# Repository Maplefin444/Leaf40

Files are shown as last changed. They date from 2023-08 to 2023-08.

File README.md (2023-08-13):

# Leaf40
This is my custom split spacebar 40% keyboard, with a custom PCB, and a 3D printed case.

***This is a work in progress, this repository houses all files pertaining to the project.***

## Parts List
- [ ] PCB
- [ ] Case
- [ ] Plate
- [ ] Keycaps
- [ ] MX-Style Switches
- [ ] SOD-123 diodes (44 total)
- [ ] Arduino Pro Micro
- [ ] Screw-in Stabilizers (2x2u)

## Layout
The layout can be found in the `Keyboard Layout` directory.

Layer 0 is the default layer, while each layer will have the corresponding layer switch keys darkened.

As of right now, non-zero layers are a ***work in progress and will change.***

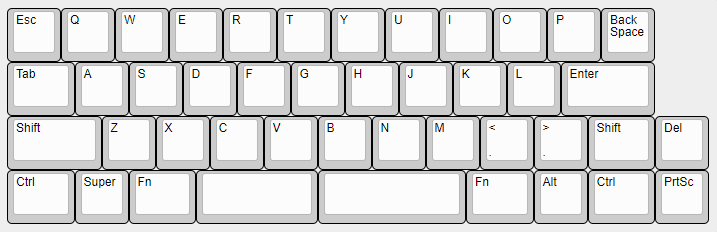
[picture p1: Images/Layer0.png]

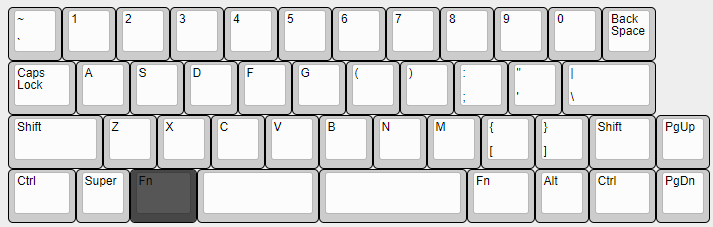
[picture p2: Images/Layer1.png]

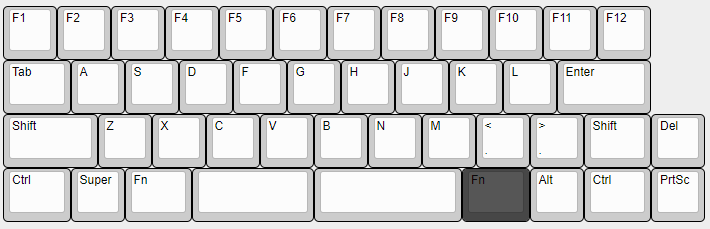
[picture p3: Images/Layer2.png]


## PCB
The PCB was designed on KiCad and can be found in the `PCB` directory.

MarbastLib is required to have the MX switch footprints.

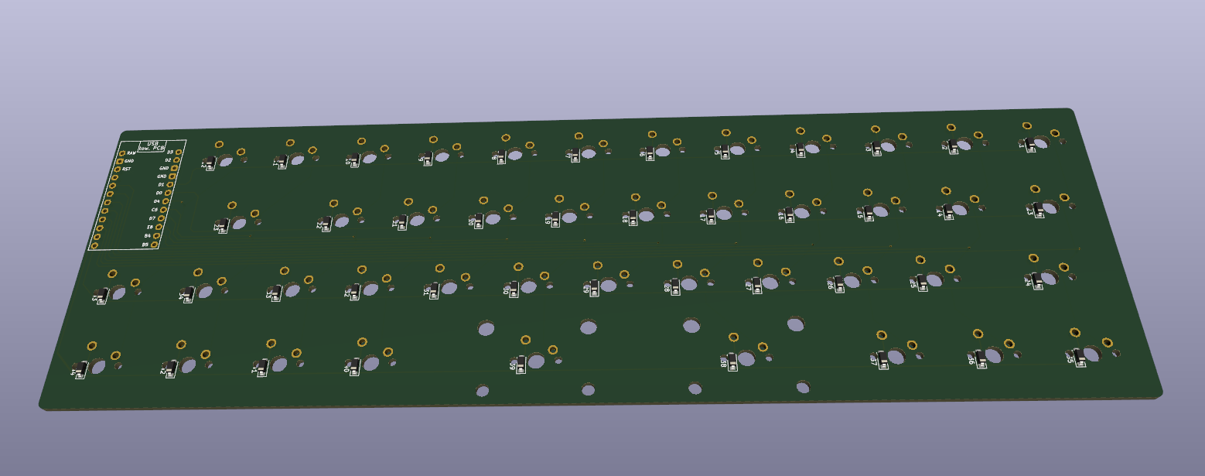
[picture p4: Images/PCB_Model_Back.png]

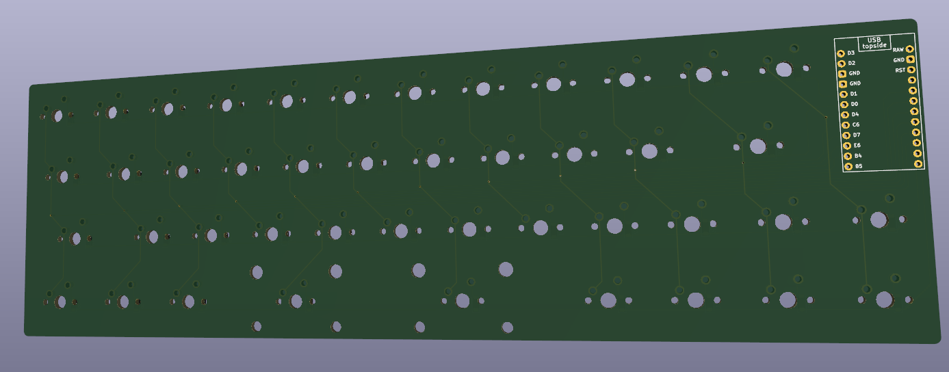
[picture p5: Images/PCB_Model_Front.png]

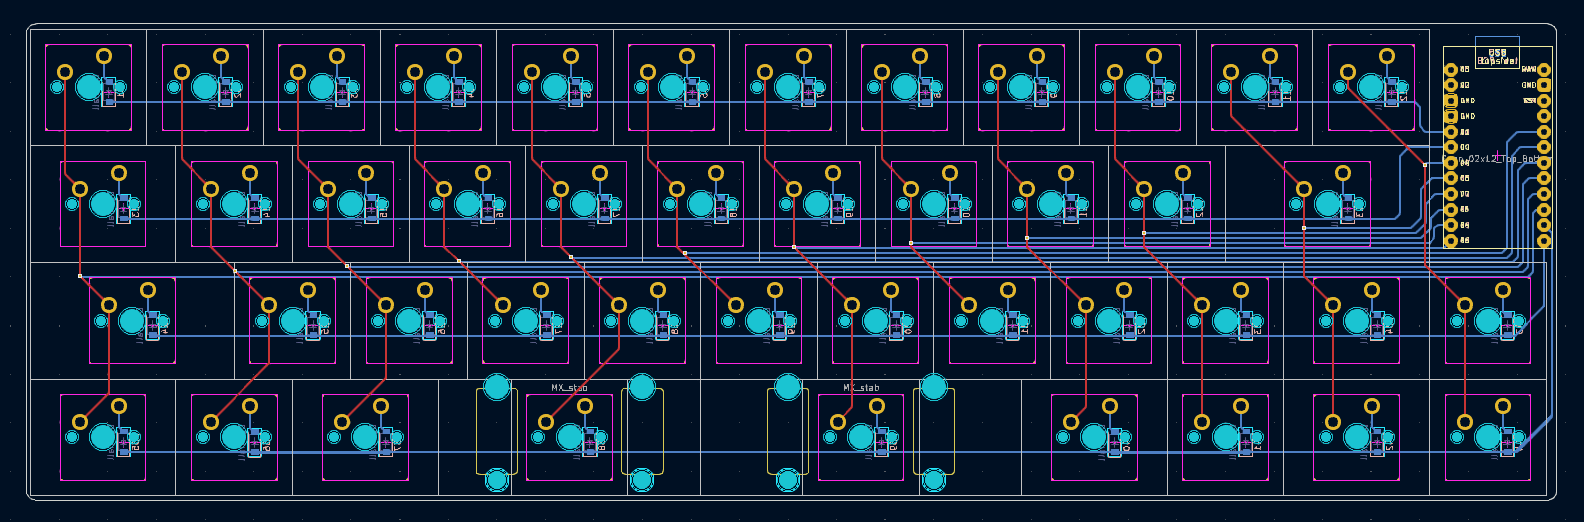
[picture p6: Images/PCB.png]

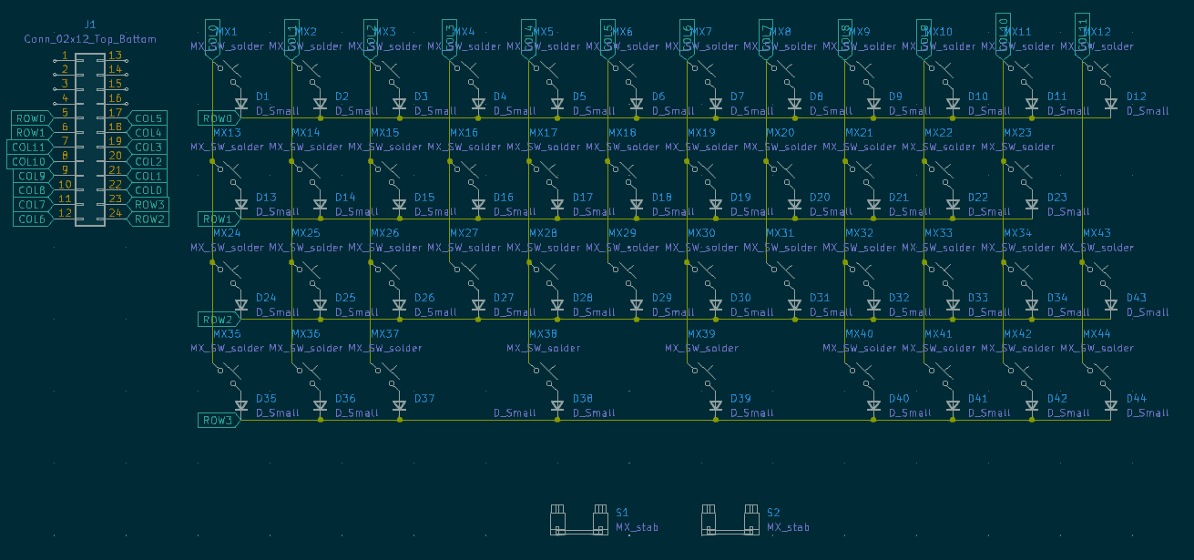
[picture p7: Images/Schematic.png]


## Firmware

This keyboard supports QMK and Vial. Both files can be found in the `Firmware` directory, `default` for regular QMK, and `vial` for the Vial firmware.

These firmwares can be flashed using the QMK Toolbox. 

The QMK firmware has ASCII art for the keyboard layouts, for ease of editing.

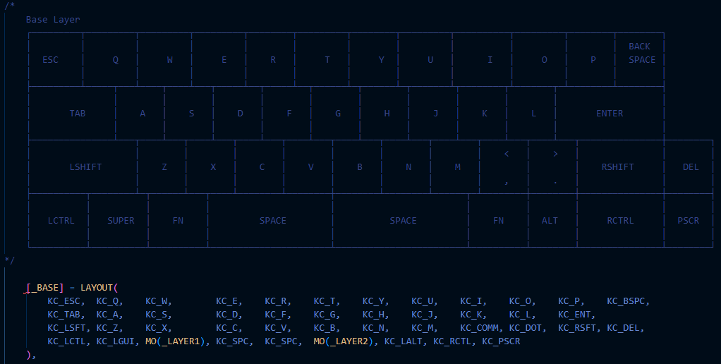
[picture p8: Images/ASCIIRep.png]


### Flashing QMK Firmware
Add the `default` keymap, info JSON, and rules file into a directory named `leaf40` under `keyboards` in your QMK directory. Then, compile using `qmk compile -kb leaf40 -km default`. Flash using QMK Toolbox.

### Flashing Vial Firmware
Add the `vial` keymap, info JSON, and rules file into a directory named `leaf40` under `keyboards` in your Vial directory. Then, compile using `make leaf40:vial` in your `vial-qmk` directory. Flash using QMK Toolbox.

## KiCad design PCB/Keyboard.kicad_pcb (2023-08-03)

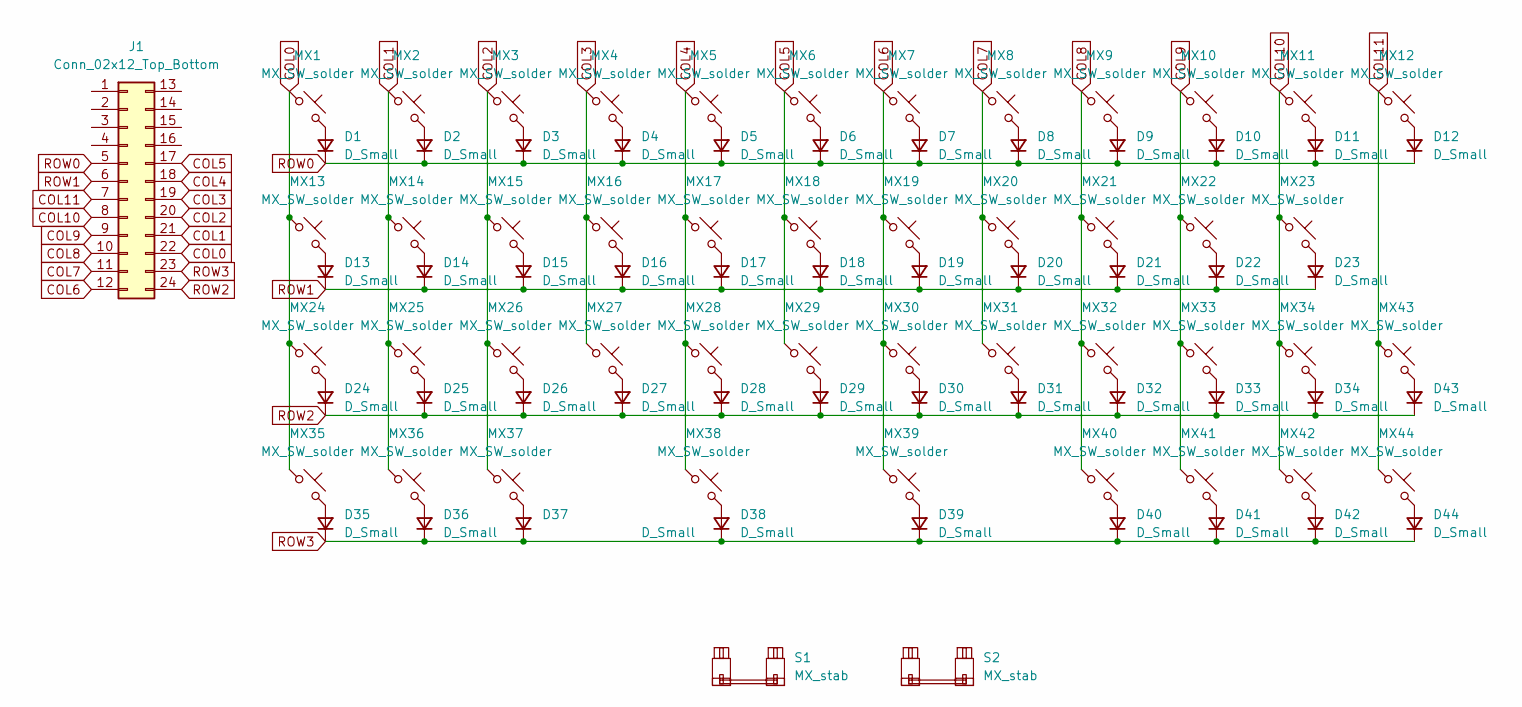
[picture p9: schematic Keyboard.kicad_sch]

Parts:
D1, D2, D3, D4, D5, D6, D7, D8, D9, D10, D11, D12, D13, D14, D15, D16, D17, D18, D19, D20, D21, D22, D23, D24, D25, D26, D27, D28, D29, D30, D31, D32, D33, D34, D35, D36, D37, D38, D39, D40, D41, D42, D43, D44: D_Small; D_SOD-123
J1: Conn_02x12_Top_Bottom; ProMicro_Reversible_Single
MX1, MX2, MX3, MX4, MX5, MX6, MX7, MX8, MX9, MX10, MX11, MX12, MX14, MX15, MX16, MX17, MX18, MX19, MX20, MX21, MX22, MX25, MX26, MX27, MX28, MX29, MX30, MX31, MX32, MX33, MX36, MX38, MX39, MX41, MX43, MX44: MX_SW_solder; SW_MX_1u
MX13, MX34, MX35, MX37, MX40, MX42: MX_SW_solder; SW_MX_1.25u
MX23, MX24: MX_SW_solder; SW_MX_1.75u
S1: MX_stab; STAB_MX_2.25u
S2: MX_stab; STAB_MX_2.75u

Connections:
COL0: J1.22, MX1.1, MX13.1, MX24.1, MX35.1
COL1: J1.21, MX2.1, MX14.1, MX25.1, MX36.1
COL2: J1.20, MX3.1, MX15.1, MX26.1, MX37.1
COL3: J1.19, MX4.1, MX16.1, MX27.1
COL4: J1.18, MX5.1, MX17.1, MX28.1, MX38.1
COL5: J1.17, MX6.1, MX18.1, MX29.1
COL6: J1.12, MX7.1, MX19.1, MX30.1, MX39.1
COL7: J1.11, MX8.1, MX20.1, MX31.1
COL8: J1.10, MX9.1, MX21.1, MX32.1, MX40.1
COL9: J1.9, MX10.1, MX22.1, MX33.1, MX41.1
COL10: J1.8, MX11.1, MX23.1, MX34.1, MX42.1
COL11: J1.7, MX12.1, MX43.1, MX44.1
unnamed: D1.2 (A), MX1.2
unnamed: D2.2 (A), MX2.2
unnamed: D3.2 (A), MX3.2
unnamed: D4.2 (A), MX4.2
unnamed: D5.2 (A), MX5.2
unnamed: D6.2 (A), MX6.2
unnamed: D7.2 (A), MX7.2
unnamed: D8.2 (A), MX8.2
unnamed: D9.2 (A), MX9.2
unnamed: D10.2 (A), MX10.2
unnamed: D11.2 (A), MX11.2
unnamed: D12.2 (A), MX12.2
unnamed: D13.2 (A), MX13.2
unnamed: D14.2 (A), MX14.2
unnamed: D15.2 (A), MX15.2
unnamed: D16.2 (A), MX16.2
unnamed: D17.2 (A), MX17.2
unnamed: D18.2 (A), MX18.2
unnamed: D19.2 (A), MX19.2
unnamed: D20.2 (A), MX20.2
unnamed: D21.2 (A), MX21.2
unnamed: D22.2 (A), MX22.2
unnamed: D23.2 (A), MX23.2
unnamed: D24.2 (A), MX24.2
unnamed: D25.2 (A), MX25.2
unnamed: D26.2 (A), MX26.2
unnamed: D27.2 (A), MX27.2
unnamed: D28.2 (A), MX28.2
unnamed: D29.2 (A), MX29.2
unnamed: D30.2 (A), MX30.2
unnamed: D31.2 (A), MX31.2
unnamed: D32.2 (A), MX32.2
unnamed: D33.2 (A), MX33.2
unnamed: D34.2 (A), MX34.2
unnamed: D35.2 (A), MX35.2
unnamed: D36.2 (A), MX36.2
unnamed: D37.2 (A), MX37.2
unnamed: D38.2 (A), MX38.2
unnamed: D39.2 (A), MX39.2
unnamed: D40.2 (A), MX40.2
unnamed: D41.2 (A), MX41.2
unnamed: D42.2 (A), MX42.2
unnamed: D43.2 (A), MX43.2
unnamed: D44.2 (A), MX44.2
ROW0: D1.1 (K), D2.1 (K), D3.1 (K), D4.1 (K), D5.1 (K), D6.1 (K), D7.1 (K), D8.1 (K), D9.1 (K), D10.1 (K), D11.1 (K), D12.1 (K), J1.5
ROW1: D13.1 (K), D14.1 (K), D15.1 (K), D16.1 (K), D17.1 (K), D18.1 (K), D19.1 (K), D20.1 (K), D21.1 (K), D22.1 (K), D23.1 (K), J1.6
ROW2: D24.1 (K), D25.1 (K), D26.1 (K), D27.1 (K), D28.1 (K), D29.1 (K), D30.1 (K), D31.1 (K), D32.1 (K), D33.1 (K), D34.1 (K), D43.1 (K), J1.24
ROW3: D35.1 (K), D36.1 (K), D37.1 (K), D38.1 (K), D39.1 (K), D40.1 (K), D41.1 (K), D42.1 (K), D44.1 (K), J1.23

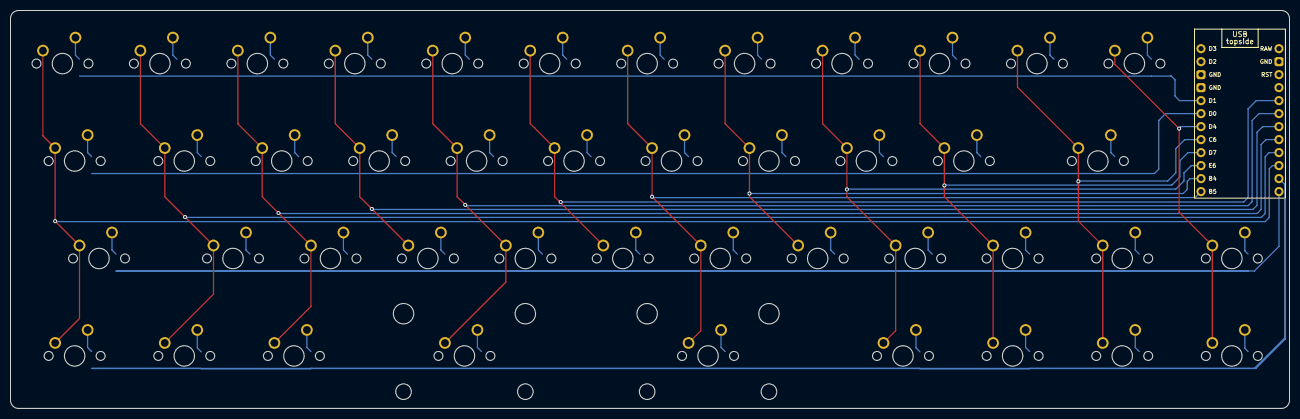
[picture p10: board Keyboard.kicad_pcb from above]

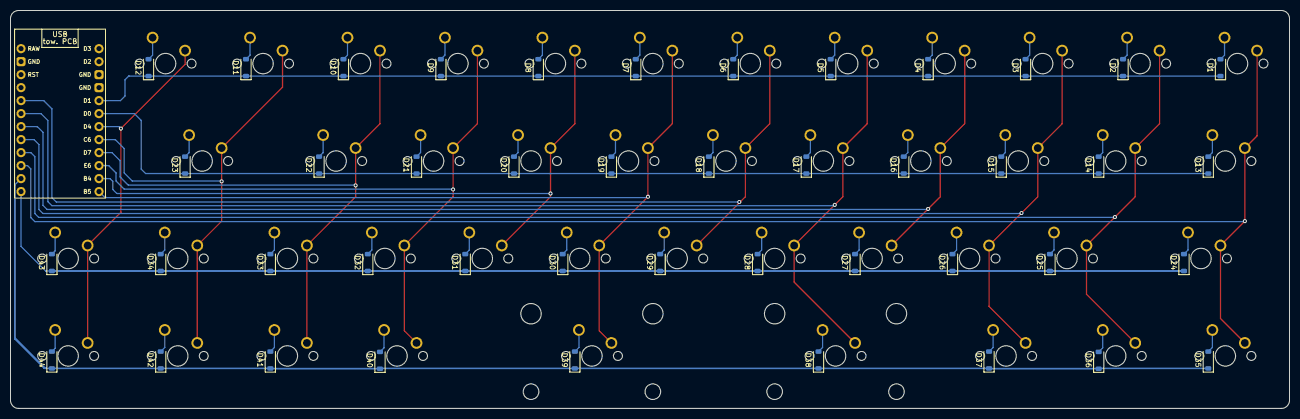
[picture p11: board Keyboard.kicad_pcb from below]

Board: 2 copper layers, 250.0 x 77.8 mm, 91 parts (44 on the bottom side), 60 nets.

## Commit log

2023-08-03 Add PCB and layers
    [Keyboard.kicad_pcb, Keyboard.kicad_sch]
2023-08-13 Add second layer switch
